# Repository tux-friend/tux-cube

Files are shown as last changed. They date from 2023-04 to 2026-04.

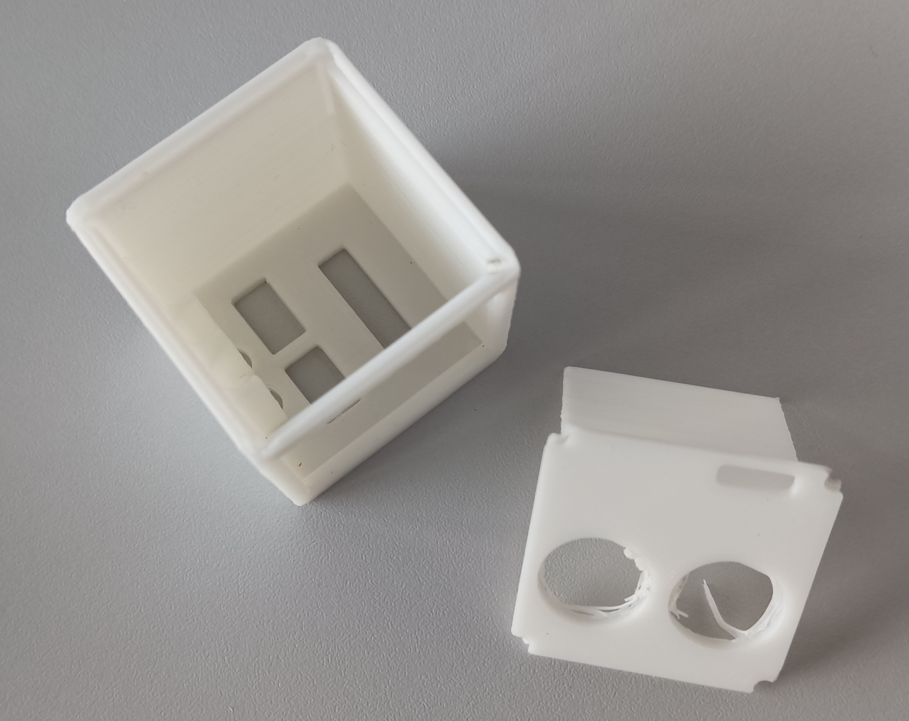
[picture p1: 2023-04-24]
case_v01.jpg

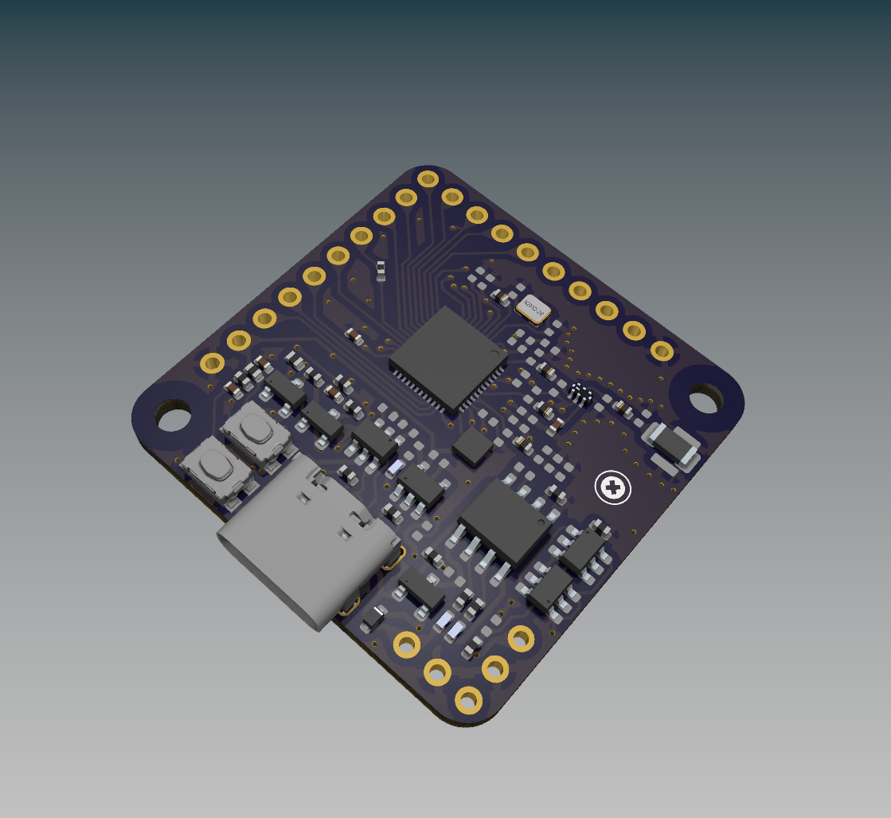
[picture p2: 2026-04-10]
board_front_2.png

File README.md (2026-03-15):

# Physics Sensor Cube ESP32-Tux³

11.04.23 Idea for own ESP32 PCB Design  
15.04.23 First sketches with KiCad  
16.04.23 Idea for physics sensor cube Tux³ and first sketches  
17.04.23 Design and order of v0.1 PCB  
22.04.23 First prototype and proof of concept  
23.04.23 Case v0.1  
25.04.23 Design and order of v0.2 PCB  
25.04.23 Case v0.2  
29.04.23 Software v0.1  
03.05.23 Arrival of PCB v0.1 + v0.2  
10.05.23 Arrival of all parts for PCB, first working ESP32-C3 board  
11.05.23 Order of 30 pcs v0.2 PCB on JLCPCB  
12.05.23 Forth ESP32-C3 board completed  
13.05.23 Case v0.3  
14.05.23 First full prototype &rarr; case too small  
17.05.23 Case v0.4  
21.05.23 ESP32-C3-Tux Mini PCB 20x20mm  
22.05.23 Case v0.5  
27.05.23 Finished DIY Reflow Heat Plate  
31.05.23 Put ESP32-Tux on Tindie and got promotion by [hackster.io](https://www.hackster.io/news/the-lifex-esp32-tux-mini-offers-a-tiny-path-to-energy-harvesting-experimentation-with-an-esp32-c3-0470bf924f33) :-)  
03.06.23 Finished 12 ESP32-Tux Dev boards for Tindie orders  
13.02.24 Designed a ESP32-Tux Board with TP4056 Charging circuit  
15.03.26 Finally got time to get back in the project and designed a new Dev Board with ESP32-C5 chip  

This is an idea I had for some time after playing around with the ESP32 together with sensors, micropython and Phyphox. I started designing a PCB by my own for an ESP32-C3 chip. I want it to be as small as possible and also solar powered. The cube should be energy ,self-sufficient' and used for teaching physics. 

The cube should have the following sensors:
- Temperature, pressure and humidity sensor &rarr; BME280
- Gyroscope for acceleration and orientation measurements &rarr; MPU9250
- Optical/Light sensor (measuring Lux) &rarr; VEML7700
- 2 connectors for temperature probes (DS18B20)
- Voltage and current meter &rarr; INA219
- Time of flight sensor for measuring distances &rarr; VL53L1X
- optional: magnetometer & microphone for sound measurements

In addition the cube should have:
- OLED Display for showing current measurement data/sensor
- RGB-LED (e.g. for showing battery status)
- Push button for changing the sensor/measurement
- Solar cell and LiPo battery
- Pin-header for connecting to cube to a breadboard and use the GPIO Pins
- Mounting nut for placing the cube on a tripod
- On/Off-Button
- optional: buzzer for sound output

I aim for a 35x35x35mm cube with 3D printed case. The case should be robust - so that it can fall from a building and be undamaged... Hope to be able to do this project. 

My inspiration come from the [ESP32-Picoclick-C3](https://github.com/makermoekoe/Picoclick-C3), [BQ25504 Solar Cell LiPo Charger](https://hackaday.io/project/158837-ultra-low-power-lipo-charger-via-energy-harvesting), [01Space-ESP32-C3](https://github.com/01Space/ESP32-C3-0.42LCD) and the [Wemos C3 Pico](https://www.wemos.cc/en/latest/c3/c3_pico.html).

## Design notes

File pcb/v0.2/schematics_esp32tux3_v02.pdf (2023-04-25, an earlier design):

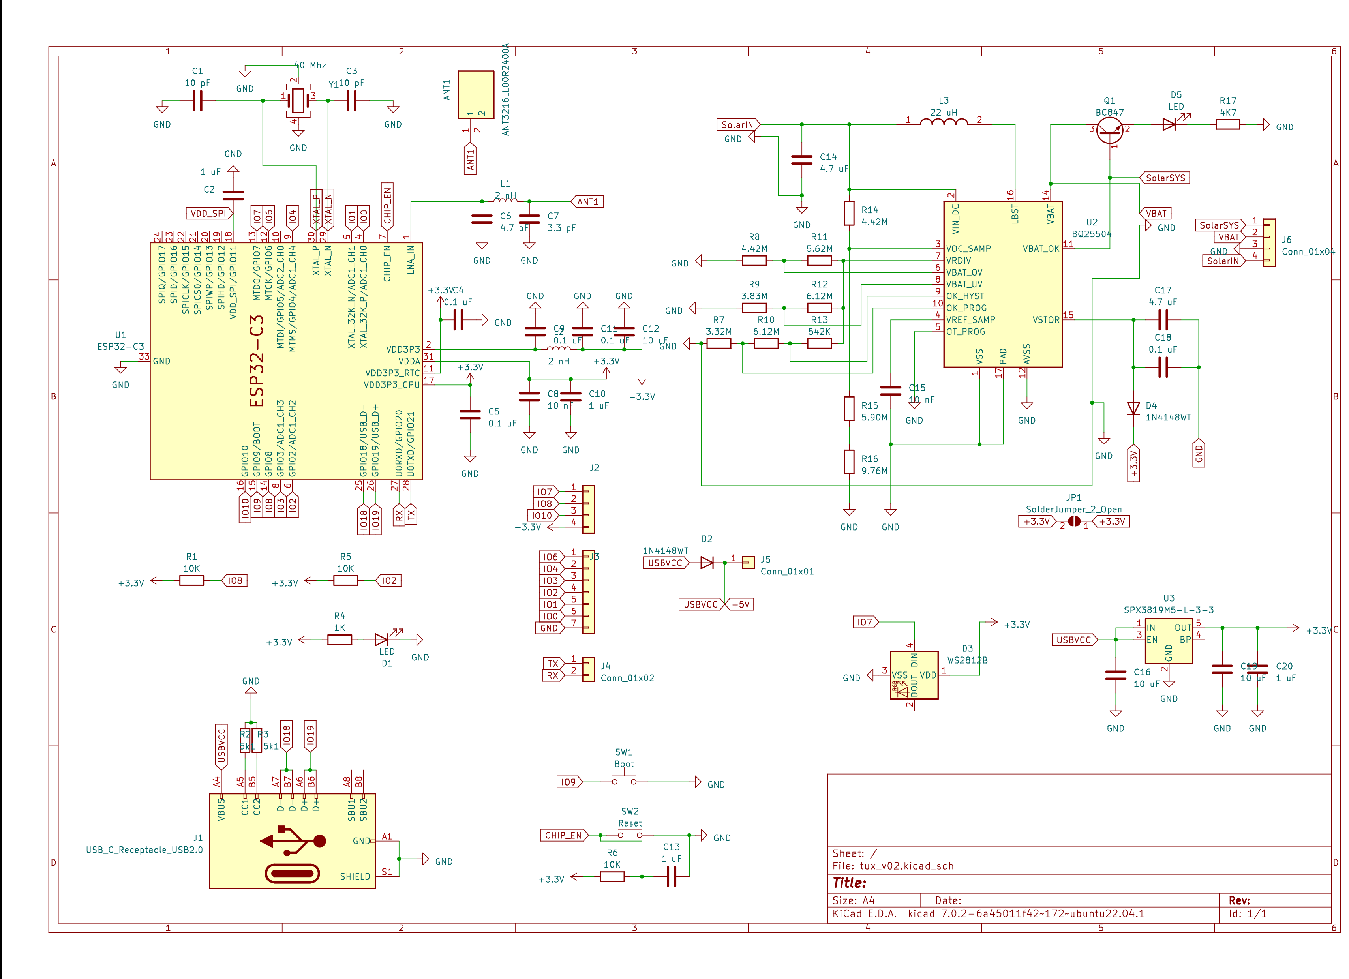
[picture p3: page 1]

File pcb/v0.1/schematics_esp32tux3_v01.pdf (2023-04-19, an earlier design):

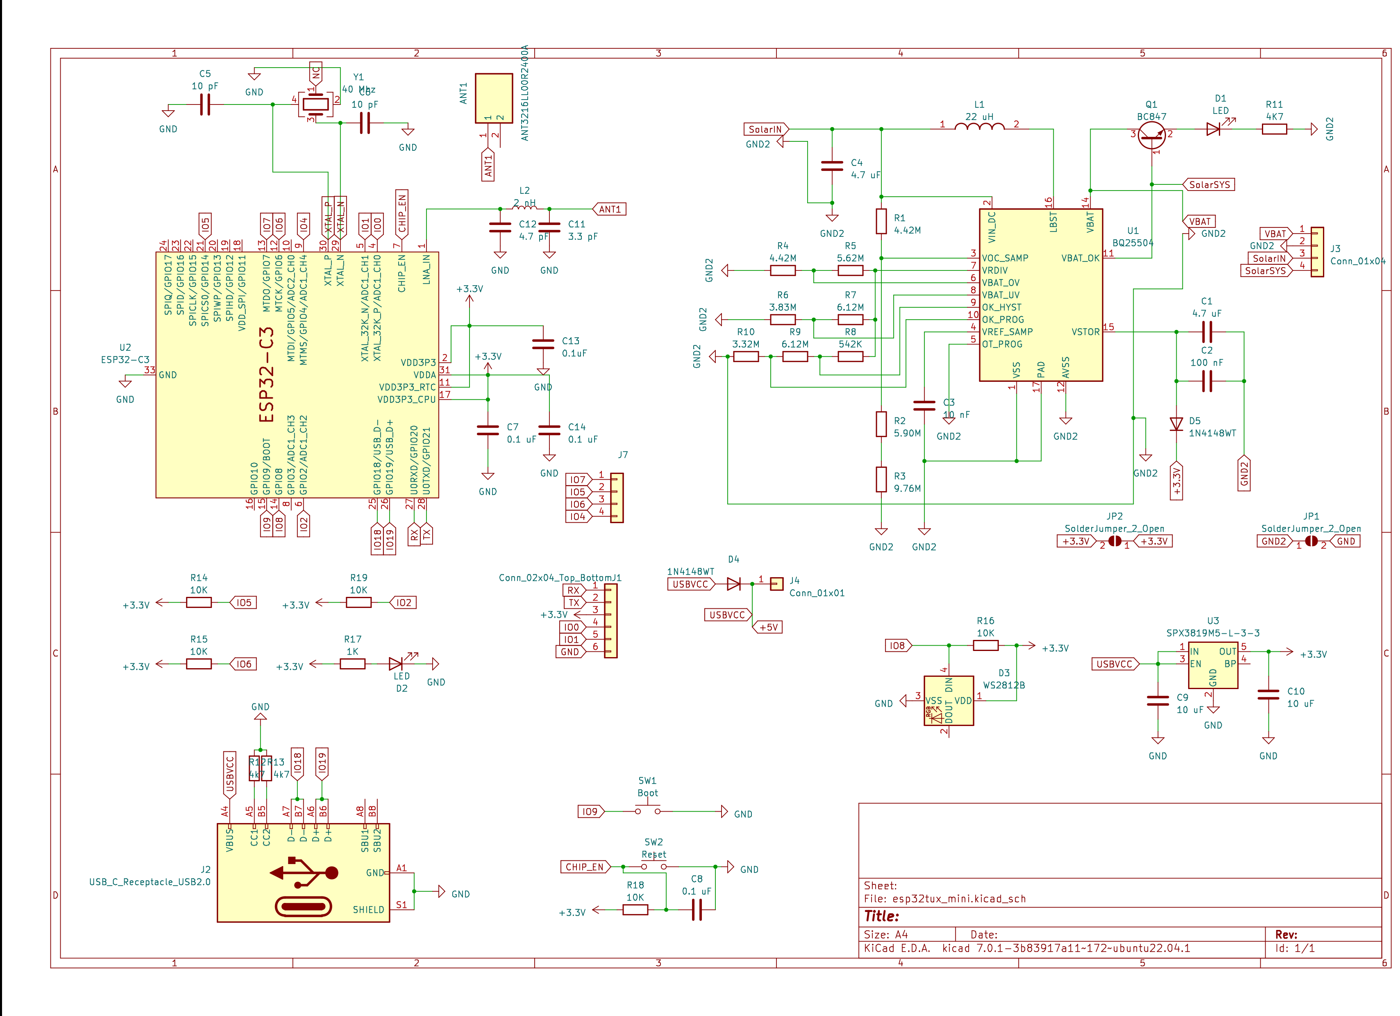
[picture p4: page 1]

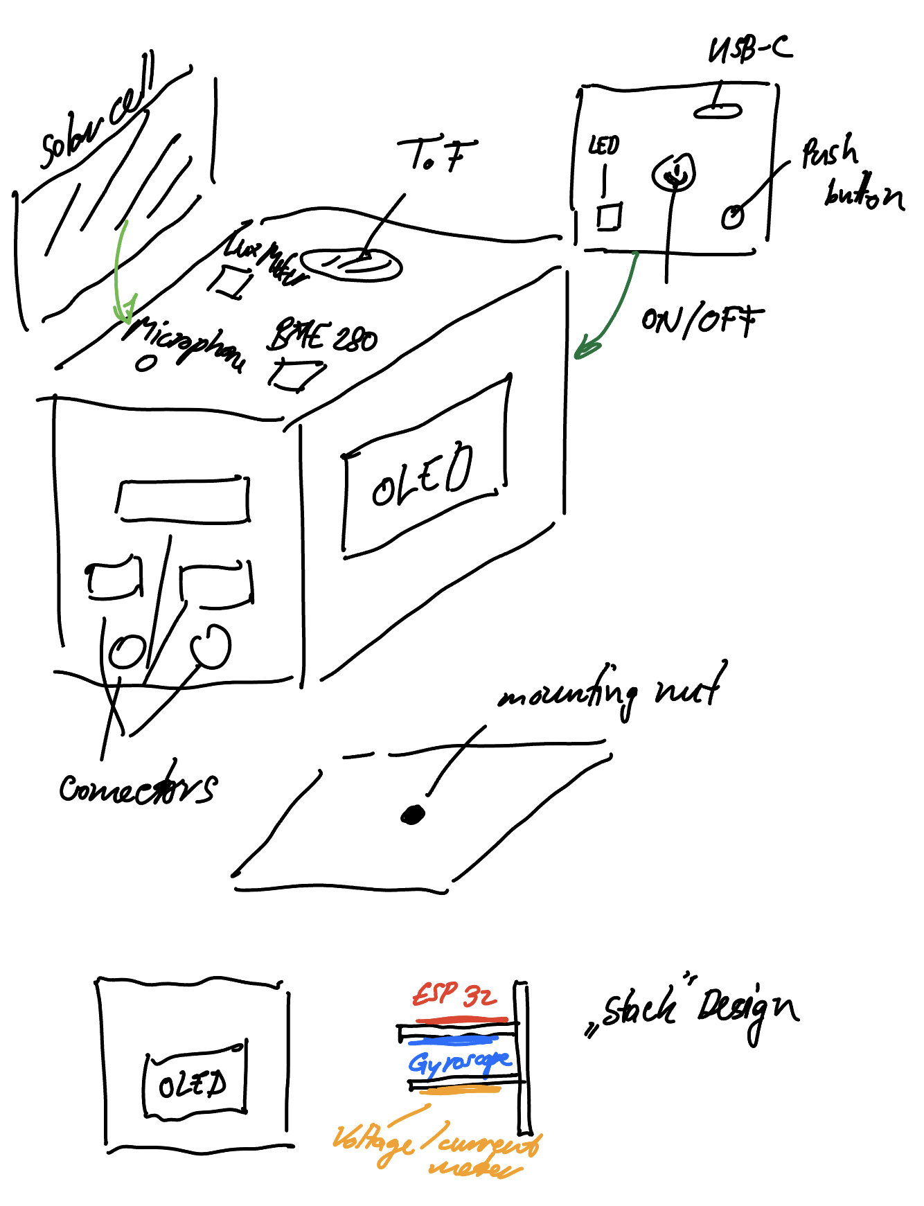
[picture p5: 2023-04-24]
idea_sketch_tux_cube.png

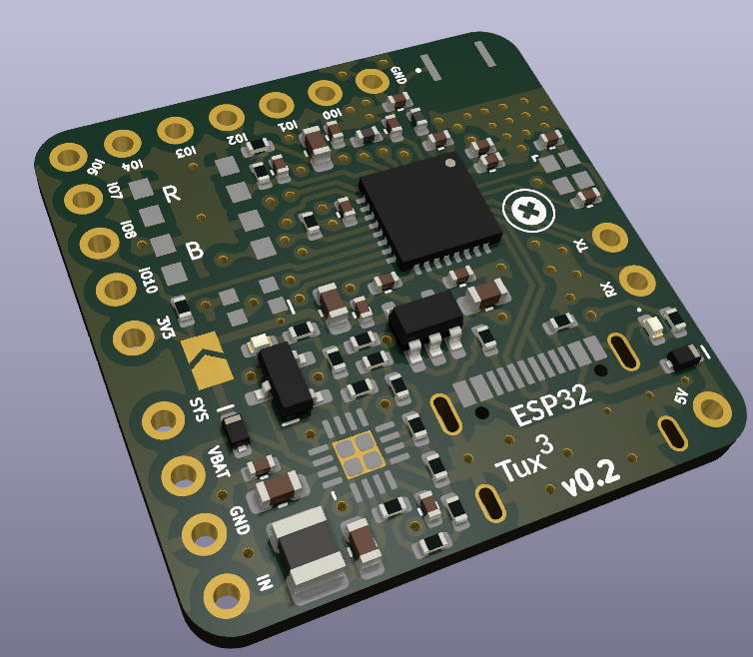
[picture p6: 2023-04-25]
tux_pcb_v02.png

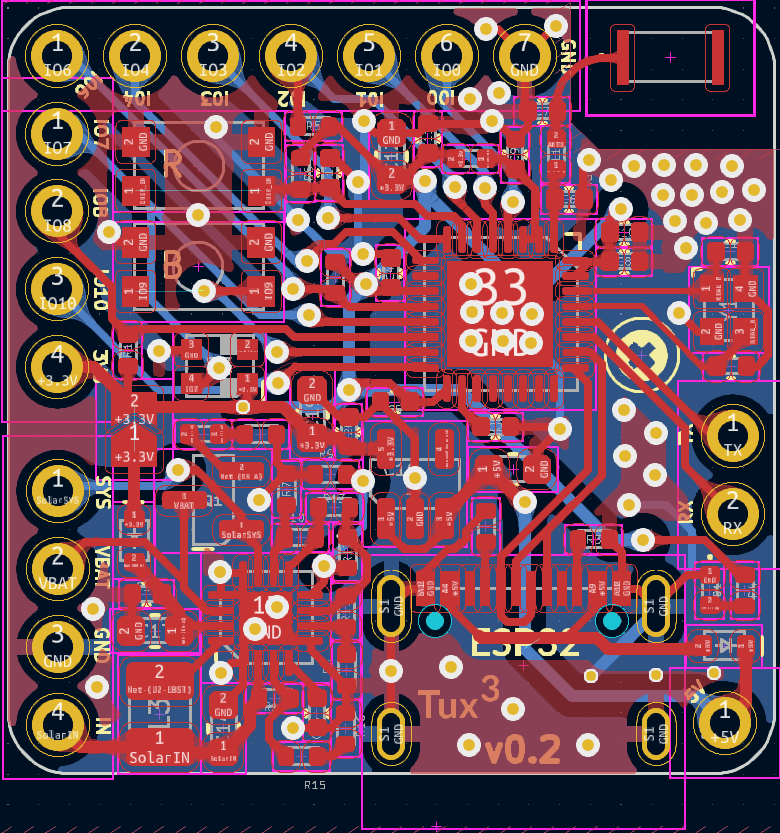
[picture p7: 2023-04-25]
routing_pcb_v02.png

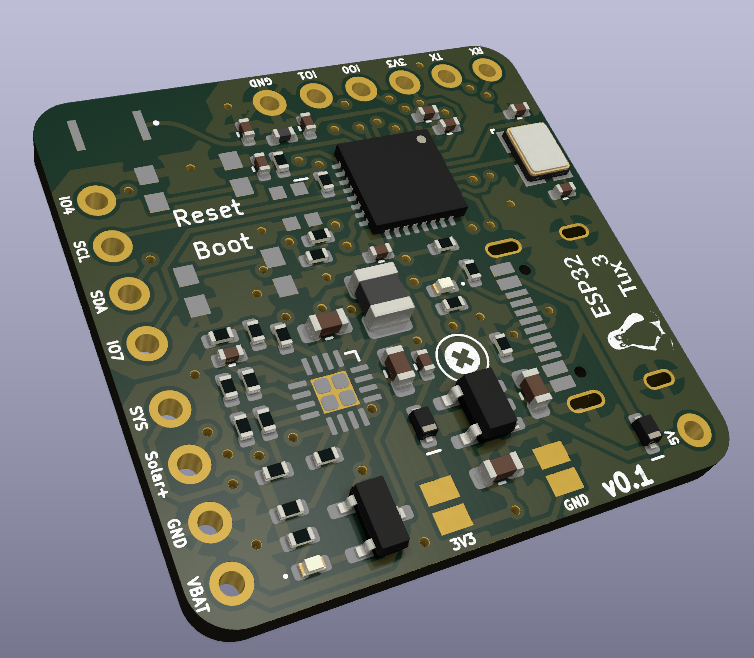
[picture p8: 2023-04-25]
tux_pcb_v01.png

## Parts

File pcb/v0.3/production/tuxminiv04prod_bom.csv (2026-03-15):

Designator | Footprint | Quantity | Value | LCSC Part #
ANT1 | Johanson_2450AT18x100 | 1 | ANT3216LL00R2400A
C1, C14, C15, C19, C2, C27 | 0402 | 6 | 10uF
C10, C11 | 0402 | 2 | 1.2pF
C12 | 0402 | 1 | 1nF
C13, C16, C18, C29 | 0402 | 4 | 1uF
C17, C22, C23, C26, C28 | 0402 | 5 | 0.1uF
C20 | 0402 | 1 | 0.3pF
C21 | 0402 | 1 | 0.8pF
C24 | 0402 | 1 | 2.6pF
C25 | 0402 | 1 | 3.0pF
C3 | 0402 | 1 | 15pF
C31 | 0402 | 1 | 10nF
C4, C5 | 0402 | 2 | 10pF
C6, C7 | 0402 | 2 | 1pF
C8, C9 | 0402 | 2 | 2.2pF
D2, D4, D5 | 0402 | 3 | LED
D6 | D_SOD-523 | 1 | SS34
D7 | LED_SK6812_EC15_1.5x1.5mm | 1 | SK6805
FL1 | LFD182G45DCHD277 | 1 | LFD182G45DCHD277
J1 | USB_C_Receptacle_Palconn_UTC16-G | 1 | USB_C_Receptacle_USB2.0_16P
J3 | PinHeader_1x09_P2.54mm_Vertical | 1 | Conn_01x09
J4 | PinHeader_1x10_P2.54mm_Vertical | 1 | Conn_01x10
J6, J7 | PinHeader_1x02_P2.54mm_Vertical | 2 | Conn_01x02
J8 | PinHeader_1x03_P2.54mm_Vertical | 1 | Conn_01x03
L1 | 0402 | 1 | 24nH
L2, L3, L4 | 0402 | 3 | 2.8nH
L5 | 0402 | 1 | 2.0nH
Q1 | SOT-23 | 1 | DMG1045U
Q2 | SOT-23 | 1 | Si2301CDS
Q3 | SOT-23 | 1 | 2N7002
R1, R2, R7, R8, R9 | 0402 | 5 | 5K1
R10, R13, R14, R15, R16, R5, R6 | 0402 | 7 | 10K
R11 | 0402 | 1 | 1k
R12 | 0402 | 1 | 1k2
R17 | 0402 | 1 | 100K
R18 | 0402 | 1 | 499
R3, R4 | 0402 | 2 | 22
SW1 | SW_Push_1P1T_NO_CK_KMR2 | 1 | Boot
SW2 | SW_Push_1P1T_NO_CK_KMR2 | 1 | Reset
U1 | QFN-48-1EP_6x6mm_P0.4mm_EP4.6x4.6mm | 1 | ESP32-C5
U2 | SOT-23-6 | 1 | USBLC6-2SC6
U4 | SOIC-8-1EP_3.9x4.9mm_P1.27mm_EP2.29x3mm | 1 | TP4056
U5 | SOT-23-6 | 1 | FS8205A
U6 | SOT-23-6 | 1 | DW01
U7 | SOT-23-5 | 1 | XC6220B331MR
Y1 | Crystal_SMD_2016-4Pin_2.0x1.6mm | 1 | Crystal_GND24

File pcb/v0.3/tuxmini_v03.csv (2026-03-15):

Reference | Qty | Value | DNP | Exclude from BOM | Exclude from Board | Footprint
ANT1 | 1 | ANT3216LL00R2400A |  |  |  | RF_Antenna:Johanson_2450AT18x100
C1,C2,C14,C15,C19,C27 | 6 | 10uF |  |  |  | Capacitor_SMD:C_0402_1005Metric
C3 | 1 | 15pF |  |  |  | Capacitor_SMD:C_0402_1005Metric
C4,C5 | 2 | 10pF |  |  |  | Capacitor_SMD:C_0402_1005Metric
C6,C7 | 2 | 1pF |  |  |  | Capacitor_SMD:C_0402_1005Metric
C8,C9 | 2 | 2.2pF |  |  |  | Capacitor_SMD:C_0402_1005Metric
C10,C11 | 2 | 1.2pF |  |  |  | Capacitor_SMD:C_0402_1005Metric
C12 | 1 | 1nF |  |  |  | PCM_SparkFun-Capacitor:C_0402_1005Metric
C13,C16,C18,C29 | 4 | 1uF |  |  |  | Capacitor_SMD:C_0402_1005Metric
C17,C22,C23,C26,C28 | 5 | 0.1uF |  |  |  | Capacitor_SMD:C_0402_1005Metric
C20 | 1 | 0.3pF |  |  |  | Capacitor_SMD:C_0402_1005Metric
C21 | 1 | 0.8pF |  |  |  | Capacitor_SMD:C_0402_1005Metric
C24 | 1 | 2.6pF |  |  |  | Capacitor_SMD:C_0402_1005Metric
C25 | 1 | 3.0pF |  |  |  | Capacitor_SMD:C_0402_1005Metric
C31 | 1 | 10nF |  |  |  | Capacitor_SMD:C_0402_1005Metric
D2,D4,D5 | 3 | LED |  |  |  | LED_SMD:LED_0402_1005Metric
D6 | 1 | SS34 |  |  |  | Diode_SMD:D_SOD-523
D7 | 1 | SK6805 |  |  |  | LED_SMD:LED_SK6812_EC15_1.5x1.5mm
FL1 | 1 | LFD182G45DCHD277 |  |  |  | LFD182G45DCHD277
H1,H2 | 2 | MountingHole |  | Von Bauteilliste ausgeschlossen |  | MountingHole:MountingHole_2.5mm_Pad_Via
J1 | 1 | USB_C_Receptacle_USB2.0_16P |  |  |  | Connector_USB:USB_C_Receptacle_Palconn_UTC16-G
J3 | 1 | Conn_01x09 |  |  |  | Connector_PinHeader_2.54mm:PinHeader_1x09_P2.54mm_Vertical
J4 | 1 | Conn_01x10 |  |  |  | Connector_PinHeader_2.54mm:PinHeader_1x10_P2.54mm_Vertical
J6,J7 | 2 | Conn_01x02 |  |  |  | Connector_PinHeader_2.54mm:PinHeader_1x02_P2.54mm_Vertical
J8 | 1 | Conn_01x03 |  |  |  | Connector_PinHeader_2.54mm:PinHeader_1x03_P2.54mm_Vertical
L1 | 1 | 24nH |  |  |  | Inductor_SMD:L_0402_1005Metric
L2,L3,L4 | 3 | 2.8nH |  |  |  | Inductor_SMD:L_0402_1005Metric
L5 | 1 | 2.0nH |  |  |  | Inductor_SMD:L_0402_1005Metric
Q1 | 1 | DMG1045U |  |  |  | PCM_Package_TO_SOT_SMD_AKL:SOT-23
Q2 | 1 | Si2301CDS |  |  |  | PCM_Package_TO_SOT_SMD_AKL:SOT-23
Q3 | 1 | 2N7002 |  |  |  | PCM_Package_TO_SOT_SMD_AKL:SOT-23
R1,R2,R7,R8,R9 | 5 | 5K1 |  |  |  | Resistor_SMD:R_0402_1005Metric
R3,R4 | 2 | 22 |  |  |  | Resistor_SMD:R_0402_1005Metric
R5,R6,R10,R13,R14,R15,R16 | 7 | 10K |  |  |  | PCM_Resistor_SMD_AKL:R_0402_1005Metric,Resistor_SMD:R_0402_1005Metric
R11 | 1 | 1k |  |  |  | Resistor_SMD:R_0402_1005Metric
R12 | 1 | 1k2 |  |  |  | Resistor_SMD:R_0402_1005Metric
R17 | 1 | 100K |  |  |  | PCM_Resistor_SMD_AKL:R_0402_1005Metric
R18 | 1 | 499 |  |  |  | Resistor_SMD:R_0402_1005Metric
SW1 | 1 | Boot |  |  |  | Button_Switch_SMD:SW_Push_1P1T_NO_CK_KMR2
SW2 | 1 | Reset |  |  |  | Button_Switch_SMD:SW_Push_1P1T_NO_CK_KMR2
U1 | 1 | ESP32-C5 |  |  |  | Package_DFN_QFN:QFN-48-1EP_6x6mm_P0.4mm_EP4.6x4.6mm
U2 | 1 | USBLC6-2SC6 |  |  |  | Package_TO_SOT_SMD:SOT-23-6
U4 | 1 | TP4056 |  |  |  | Package_SO:SOIC-8-1EP_3.9x4.9mm_P1.27mm_EP2.29x3mm
U5 | 1 | FS8205A |  |  |  | Package_TO_SOT_SMD:SOT-23-6
U6 | 1 | DW01 |  |  |  | Package_TO_SOT_SMD:SOT-23-6
U7 | 1 | XC6220B331MR |  |  |  | Package_TO_SOT_SMD:SOT-23-5
Y1 | 1 | Crystal_GND24 |  |  |  | Crystal:Crystal_SMD_2016-4Pin_2.0x1.6mm

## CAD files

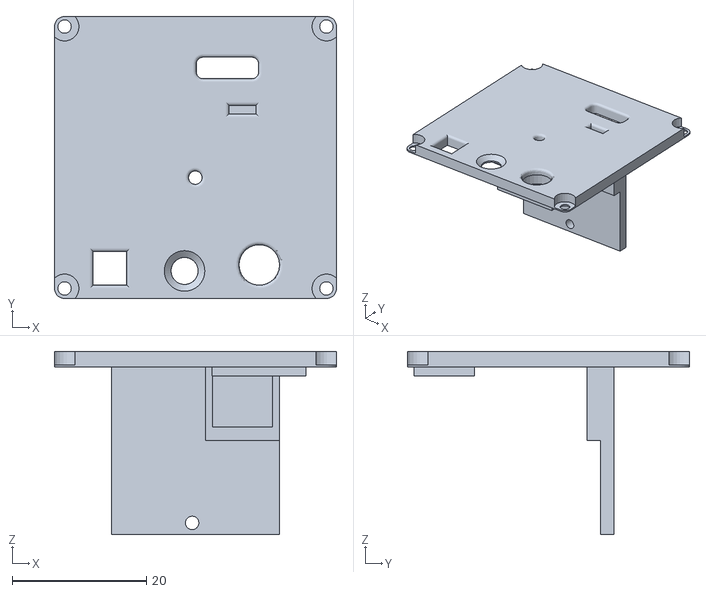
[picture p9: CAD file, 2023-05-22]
case/cube_inside.stl
42.0 x 42.0 x 27.3

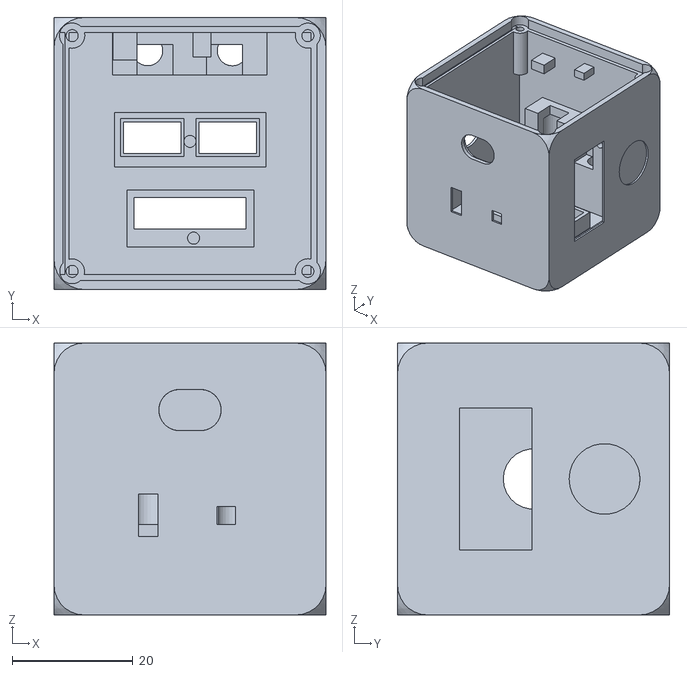
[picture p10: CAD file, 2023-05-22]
case/cube_outside.stl
45.0 x 45.0 x 45.0

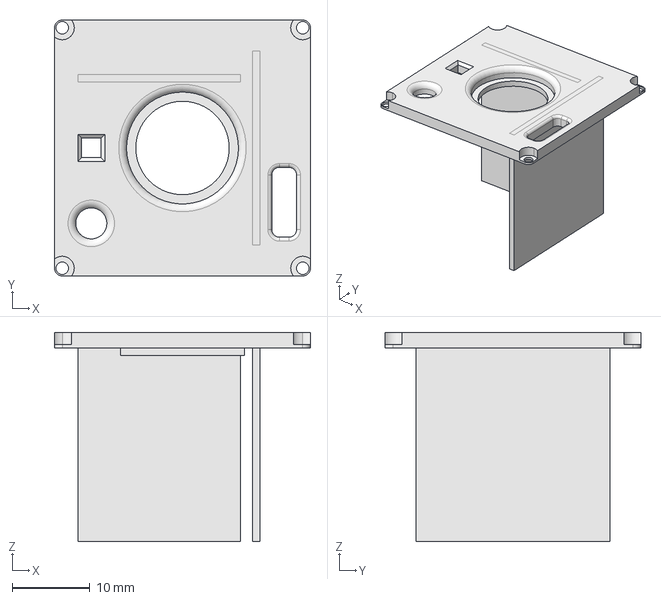
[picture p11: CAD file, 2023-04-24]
case/TuxCube3_case_v01.FCStd
33.0 x 33.0 x 27.0 mm

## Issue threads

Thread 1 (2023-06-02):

Quiescent current from the LED Pixel?

EternityForest, 2023-06-02:
As I understand it those chips use 250uA or so when idle?  Seems like a significant load in this kind of application.

Could a MOSFET be used to stop this idle drain?

tux-friend, 2023-06-03:
This is true. It's my first ESP32 PCB design and I didn't focus on power efficency - but for a revision of the board I sure will take this into consideration.
The sensor cube uses Bluetooth Low Energy and then the ESP32 uses quite a lot of power. For a 24/7 usage of the board the LED could also be soldered of or yes maybe a MOSFET.

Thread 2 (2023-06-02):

Put all the indicator LEDs under software control?

EternityForest, 2023-06-02:
Right now there's LEDs for VBAT and 3.3v power, which seems like a pretty heavy power drain, plus an aesthetic issue if they are too bright when that's not wanted.

Maybe VBAT_OK could be connected to an IO, or better yet, a 10Mohm voltage divider and 0.1uf capacitor could be used to let the ESP measure the battery with an ADC, and any indicator lights desired could be done in software?

Since there's already an addressable LED pixel, maybe that could be used, and the different battery status conditions indicated just via blink patterns.

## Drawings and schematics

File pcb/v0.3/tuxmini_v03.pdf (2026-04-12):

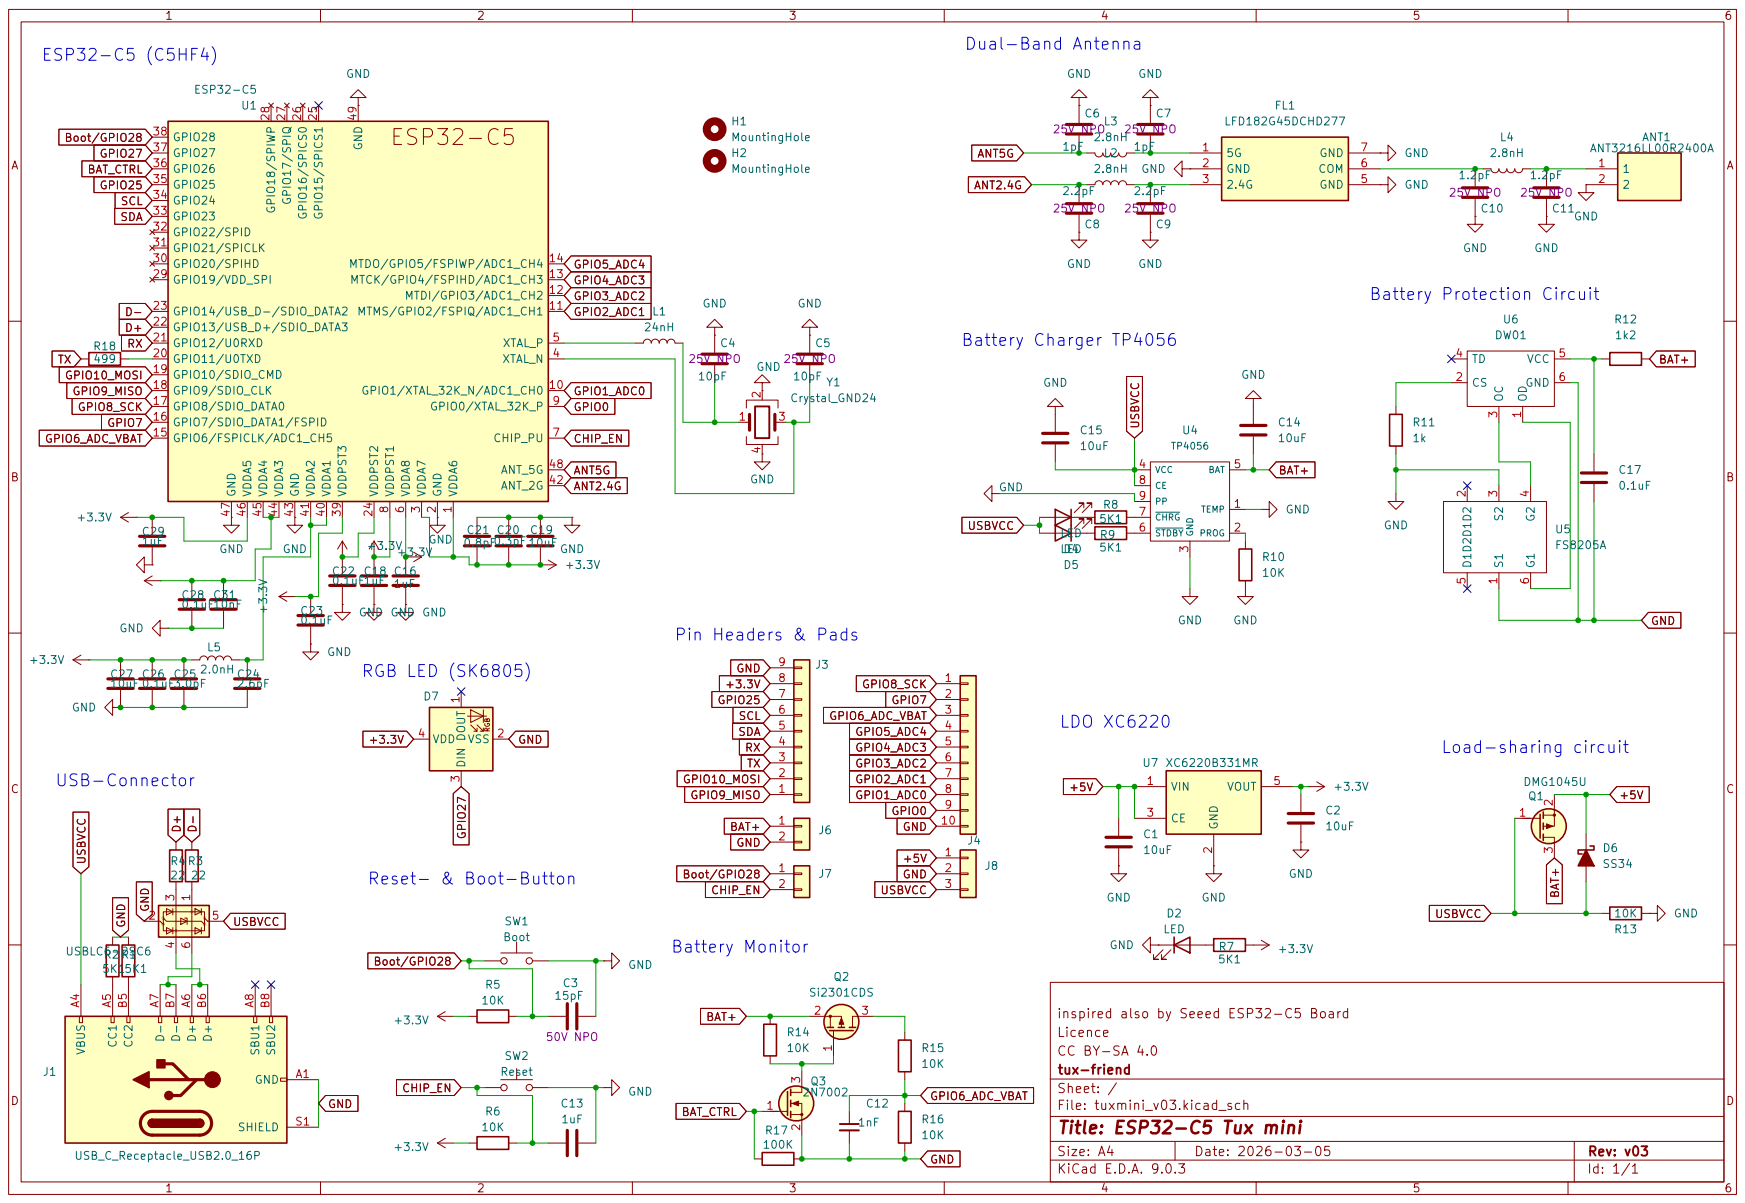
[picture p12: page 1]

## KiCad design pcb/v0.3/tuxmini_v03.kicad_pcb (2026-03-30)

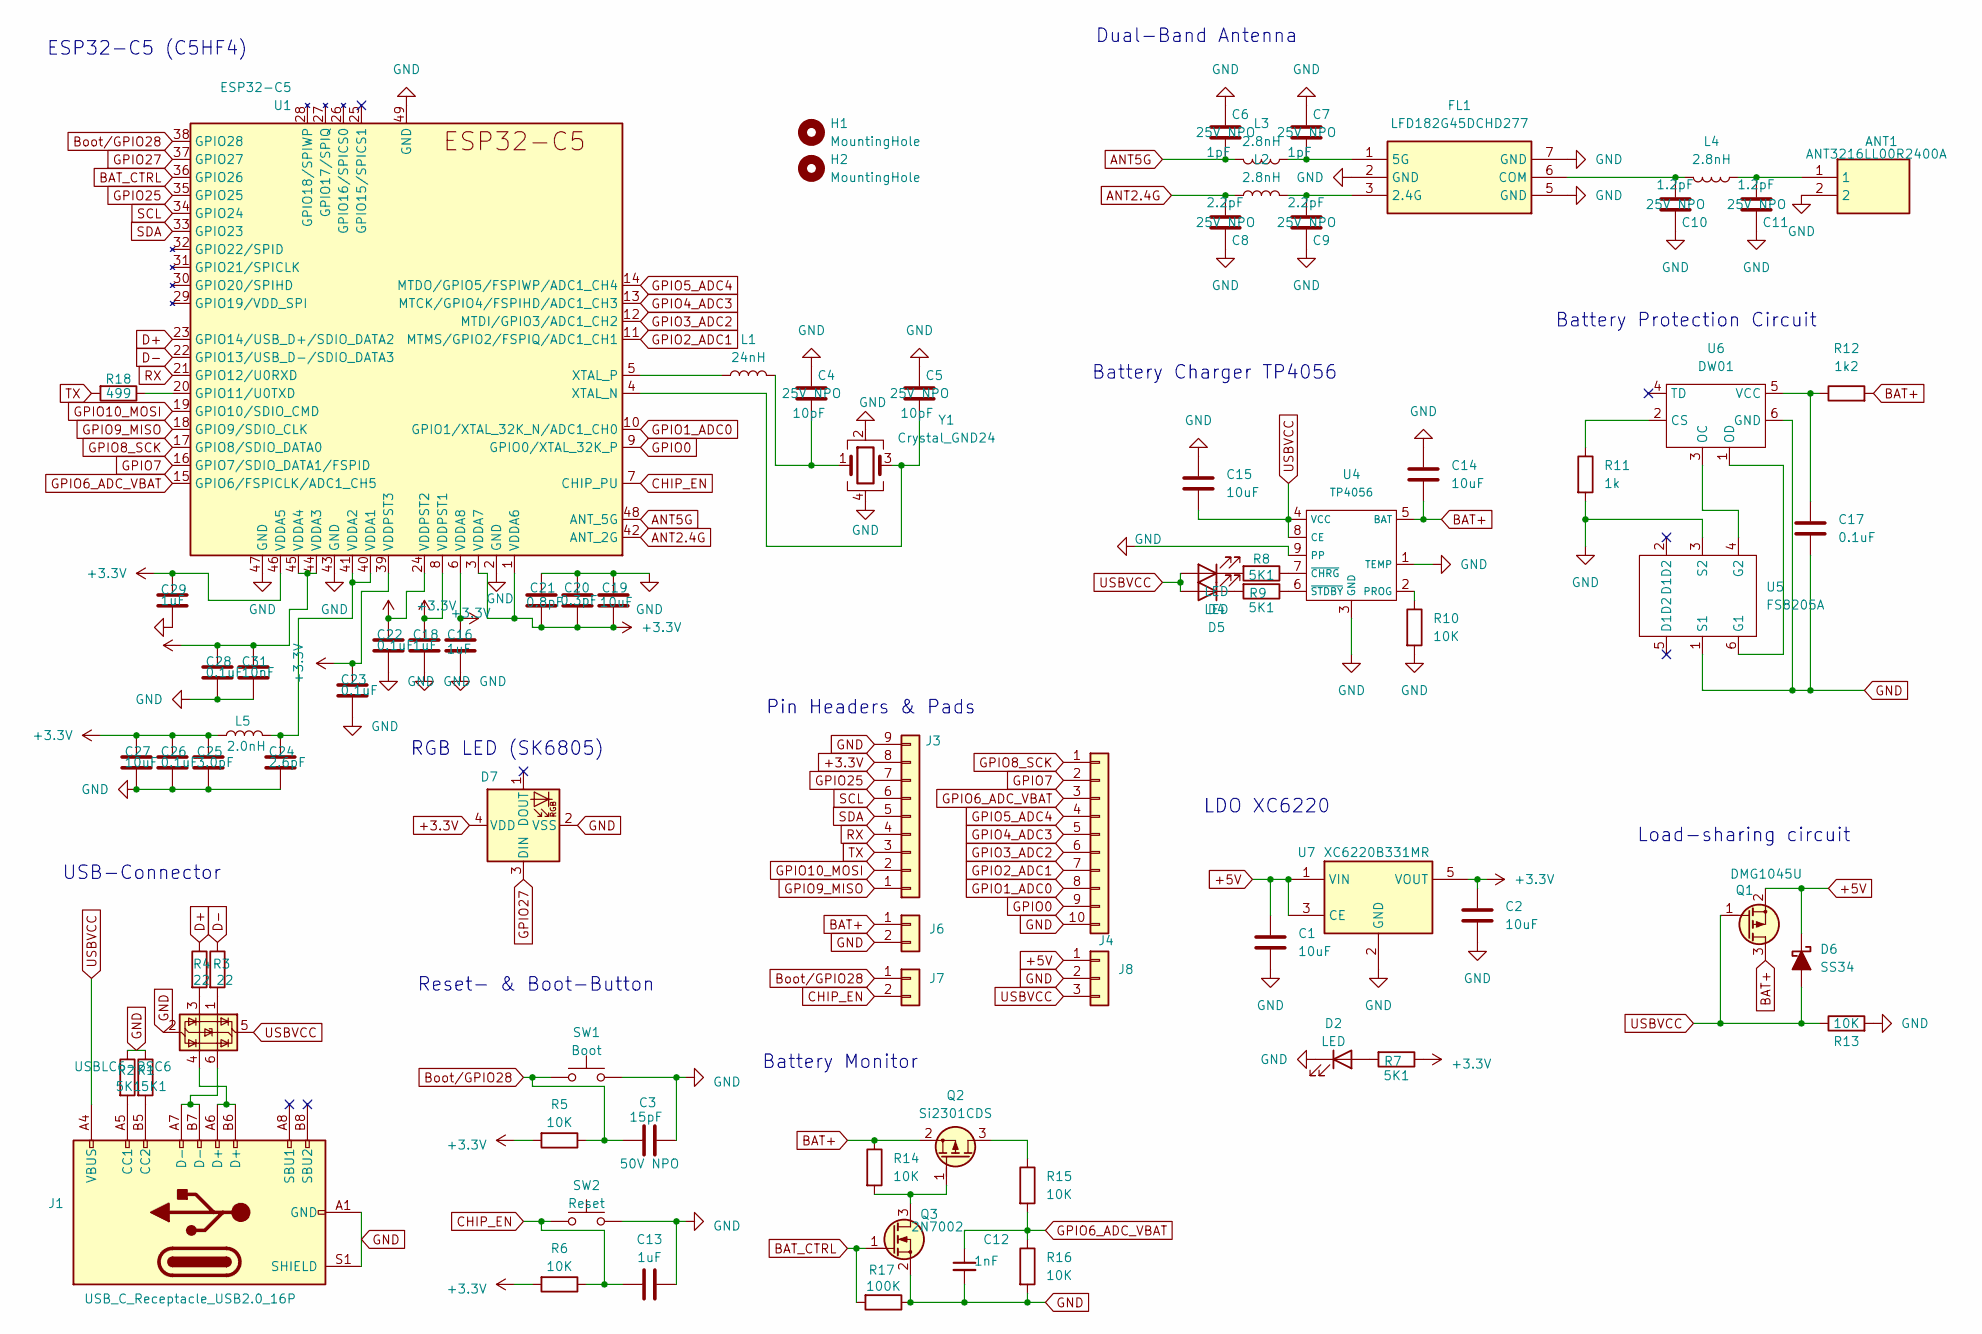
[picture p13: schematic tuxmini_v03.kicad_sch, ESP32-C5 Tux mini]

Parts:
ANT1: ANT3216LL00R2400A; Johanson_2450AT18x100; Mouser Part Number 603-ANT3216LL00R2400
C1, C2, C14, C15, C19, C27: 10uF; C_0402_1005Metric
C3: 15pF; C_0402_1005Metric
C4, C5: 10pF; C_0402_1005Metric
C6, C7: 1pF; C_0402_1005Metric
C8, C9: 2.2pF; C_0402_1005Metric
C10, C11: 1.2pF; C_0402_1005Metric
C12: 1nF; C_0402_1005Metric; Tolerance 100%
C13, C16, C18, C29: 1uF; C_0402_1005Metric
C17, C22, C23, C26, C28: 0.1uF; C_0402_1005Metric
C20: 0.3pF; C_0402_1005Metric
C21: 0.8pF; C_0402_1005Metric
C24: 2.6pF; C_0402_1005Metric
C25: 3.0pF; C_0402_1005Metric
C31: 10nF; C_0402_1005Metric
D2, D4, D5: LED; LED_0402_1005Metric
D6: SS34; D_SOD-523
D7: SK6805; LED_SK6812_EC15_1.5x1.5mm
FL1: LFD182G45DCHD277; Manufacturer_Part_Number LFD182G45DCHD277
H1, H2: MountingHole; MountingHole_2.5mm_Pad_Via
J1: USB_C_Receptacle_USB2.0_16P; USB_C_Receptacle_Palconn_UTC16-G
J3: Conn_01x09; PinHeader_1x09_P2.54mm_Vertical
J4: Conn_01x10; PinHeader_1x10_P2.54mm_Vertical
J6: Conn_01x02; PinHeader_1x02_P2.54mm_Vertical; Part Number 1-0201FBV0T
J7: Conn_01x02; PinHeader_1x02_P2.54mm_Vertical
J8: Conn_01x03; PinHeader_1x03_P2.54mm_Vertical
L1: 24nH; L_0402_1005Metric
L2, L3, L4: 2.8nH; L_0402_1005Metric
L5: 2.0nH; L_0402_1005Metric
Q1: DMG1045U; SOT-23
Q2: Si2301CDS; SOT-23
Q3: 2N7002; SOT-23
R1, R2, R7, R8, R9: 5K1; R_0402_1005Metric
R3, R4: 22; R_0402_1005Metric
R5, R6, R10, R13, R14, R15, R16: 10K; R_0402_1005Metric
R11: 1k; R_0402_1005Metric
R12: 1k2; R_0402_1005Metric
R17: 100K; R_0402_1005Metric
R18: 499; R_0402_1005Metric
SW1: Boot; SW_Push_1P1T_NO_CK_KMR2
SW2: Reset; SW_Push_1P1T_NO_CK_KMR2
U1: ESP32-C5; QFN-48-1EP_6x6mm_P0.4mm_EP4.6x4.6mm
U2: USBLC6-2SC6; SOT-23-6
U4: TP4056; SOIC-8-1EP_3.9x4.9mm_P1.27mm_EP2.29x3mm
U5: FS8205A; SOT-23-6
U6: DW01; SOT-23-6
U7: XC6220B331MR; SOT-23-5
Y1: Crystal_GND24; Crystal_SMD_2016-4Pin_2.0x1.6mm

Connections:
+3.3V: C2.1, C16.1, C18.1, C19.2, C20.2, C21.2, C22.1, C23.1, C25.1, C26.1, C27.1, C28.1, C29.1, C31.1, D7.4 (VDD), J3.8, L5.2, R5.2, R6.2, R7.1, U1.1 (VDDA6), U1.3 (VDDA7), U1.6 (VDDA8), U1.8 (VDDPST1), U1.24 (VDDPST2), U1.39 (VDDPST3), U1.44 (VDDA3), U1.45 (VDDA4), U1.46 (VDDA5), U7.5 (VOUT)
+5V: C1.1, D6.1 (K), J8.1, Q1.2 (S), U7.1 (VIN), U7.3 (CE)
ANT2.4G: C8.2, L2.2, U1.42 (ANT_2G)
ANT5G: C6.2, L3.2, U1.48 (ANT_5G)
BAT+: C14.2, J6.1, Q1.3 (D), Q2.2 (S), R12.2, R14.1, U4.5 (BAT)
BAT_CTRL: Q3.1 (G), R17.2, U1.36 (GPIO26)
Boot/GPIO28: C3.1, J7.1, R5.1, SW1.1, U1.38 (GPIO28)
CHIP_EN: C13.1, J7.2, R6.1, SW2.1, U1.7 (CHIP_PU)
D+: R4.1, U1.23 (GPIO14/USB_D+/SDIO_DATA2)
D-: R3.1, U1.22 (GPIO13/USB_D-/SDIO_DATA3)
GND: ANT1.2, C1.2, C2.2, C3.2, C4.1, C5.1, C6.1, C7.1, C8.1, C9.1, C10.1, C11.1, C12.2, C13.2, C14.1, C15.1, C16.2, C17.2, C18.2, C19.1, C20.1, C21.1, C22.2, C23.2, C24.2, C25.2, C26.2, C27.2, C28.2, C29.2, C31.2, D2.1 (K), D7.2 (VSS), FL1.2 (GND), FL1.5 (GND), FL1.7 (GND), J1.A1 (GND), J1.A12 (GND), J1.B1 (GND), J1.B12 (GND), J1.S1 (SHIELD), J3.9, J4.10, J6.2, J8.2, Q3.2 (S), R1.1, R2.1, R10.2, R11.2, R13.2, R16.2, R17.1, SW1.2, SW2.2, U1.2 (GND), U1.43 (GND), U1.47 (GND), U1.49 (GND), U2.2 (GND), U4.1 (TEMP), U4.3 (GND), U4.9 (PP), U5.1 (S1), U5.3 (S2), U6.6 (GND), U7.2 (GND), Y1.2, Y1.4
GPIO0: J4.9, U1.9 (GPIO0/XTAL_32K_P)
GPIO1_ADC0: J4.8, U1.10 (GPIO1/XTAL_32K_N/ADC1_CH0)
GPIO2_ADC1: J4.7, U1.11 (MTMS/GPIO2/FSPIQ/ADC1_CH1)
GPIO3_ADC2: J4.6, U1.12 (MTDI/GPIO3/ADC1_CH2)
GPIO4_ADC3: J4.5, U1.13 (MTCK/GPIO4/FSPIHD/ADC1_CH3)
GPIO5_ADC4: J4.4, U1.14 (MTDO/GPIO5/FSPIWP/ADC1_CH4)
GPIO6_ADC_VBAT: C12.1, J4.3, R15.2, R16.1, U1.15 (GPIO6/FSPICLK/ADC1_CH5)
GPIO7: J4.2, U1.16 (GPIO7/SDIO_DATA1/FSPID)
GPIO8_SCK: J4.1, U1.17 (GPIO8/SDIO_DATA0)
GPIO9_MISO: J3.1, U1.18 (GPIO9/SDIO_CLK)
GPIO10_MOSI: J3.2, U1.19 (GPIO10/SDIO_CMD)
GPIO25: J3.7, U1.35 (GPIO25)
GPIO27: D7.3 (DIN), U1.37 (GPIO27)
unnamed: ANT1.1, C11.2, L4.2
unnamed: C4.2, L1.2, Y1.1
unnamed: D2.2 (A), R7.2
unnamed: D4.1 (K), R8.2
unnamed: D5.1 (K), R9.2
unnamed: C9.2, FL1.3 (2.4G), L2.1
unnamed: C7.2, FL1.1 (5G), L3.1
unnamed: C10.2, FL1.6 (COM), L4.1
unnamed: J1.A5 (CC1), R2.2
unnamed: J1.B5 (CC2), R1.2
unnamed: J1.A6 (D+), J1.B6 (D+), U2.4 (I/O2)
unnamed: J1.A7 (D-), J1.B7 (D-), U2.6 (I/O1)
unnamed: Q2.3 (D), R15.1
unnamed: Q2.1 (G), Q3.3 (D), R14.2
unnamed: R3.2, U2.1 (I/O1)
unnamed: R4.2, U2.3 (I/O2)
unnamed: R18.1, U1.20 (GPIO11/U0TXD)
unnamed: C24.1, L5.1, U1.40 (VDDA1), U1.41 (VDDA2)
unnamed: C5.2, U1.4 (XTAL_N), Y1.3
unnamed: L1.1, U1.5 (XTAL_P)
unnamed: R10.1, U4.2 (PROG)
unnamed: R8.1, U4.7 (~CHRG)
unnamed: R9.1, U4.6 (~STDBY)
unnamed: U5.6 (G1), U6.1 (OD)
unnamed: U5.4 (G2), U6.3 (OC)
unnamed: R11.1, U6.2 (CS)
unnamed: C17.1, R12.1, U6.5 (VCC)
RX: J3.4, U1.21 (GPIO12/U0RXD)
SCL: J3.6, U1.34 (GPIO24)
SDA: J3.5, U1.33 (GPIO23)
TX: J3.3, R18.2
USBVCC: C15.2, D4.2 (A), D5.2 (A), D6.2 (A), J1.A4 (VBUS), J1.A9 (VBUS), J1.B4 (VBUS), J1.B9 (VBUS), J8.3, Q1.1 (G), R13.1, U2.5 (VBUS), U4.4 (VCC), U4.8 (CE)

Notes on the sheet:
Reset- & Boot-Button
Battery Monitor
Battery Protection Circuit
LDO XC6220
Load-sharing circuit
Pin Headers & Pads
RGB LED (SK6805)
USB-Connector
ESP32-C5 (C5HF4)
Battery Charger TP4056
Dual-Band Antenna

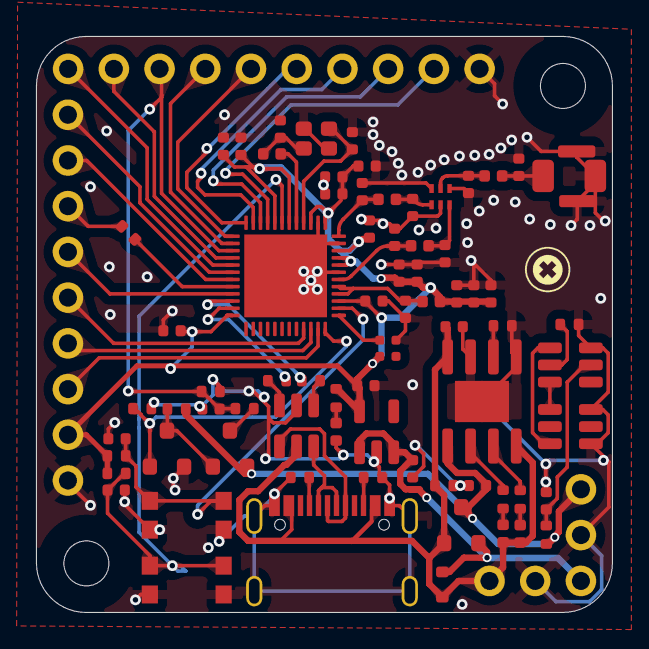
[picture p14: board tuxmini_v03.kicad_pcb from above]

Board: 2 copper layers, 32.0 x 32.0 mm, 80 parts (1 on the bottom side), 56 nets.

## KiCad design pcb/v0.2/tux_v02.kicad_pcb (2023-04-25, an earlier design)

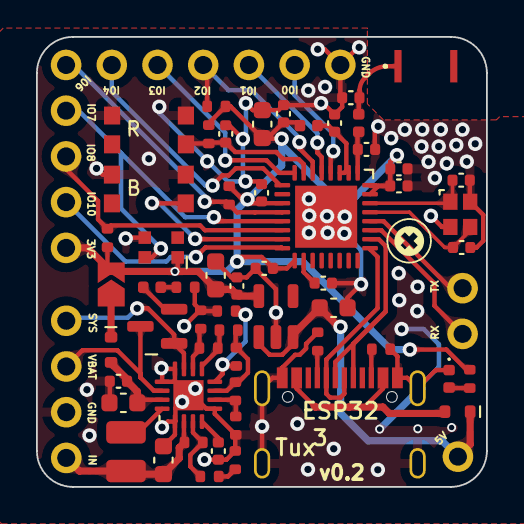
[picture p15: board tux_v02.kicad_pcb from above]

Board: 2 copper layers, 25.0 x 25.0 mm, 61 parts (0 on the bottom side), 42 nets.

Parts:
ANT1: ANT3216LL00R2400A
C1, C3: 10 pF; C_0402_1005Metric
C2, C10, C13, C20: 1 uF; C_0402_1005Metric
C4, C5, C9, C11, C18: 0.1 uF; C_0402_1005Metric
C6: 4.7 pF; C_0402_1005Metric
C7: 3.3 pF; C_0402_1005Metric
C8, C15: 10 nF; C_0402_1005Metric
C12, C16, C19: 10 uF; C_0603_1608Metric
C14, C17: 4.7 uF; C_0603_1608Metric
D1, D5: LED; LED_0402_1005Metric
D2, D4: 1N4148WT; D_SOD-523
D3: WS2812B; LED_WS2812B-2020_PLCC4_2.0x2.0mm
J1: USB_C_Receptacle_USB2.0; USB_C_Receptacle_Palconn_UTC16-G
J2: Conn_02x04_Top_Bottom; PinHeader_1x04_P2.54mm_Vertical
J3: Conn_02x04_Top_Bottom; PinHeader_1x07_P2.54mm_Vertical
J4: Conn_01x02; PinHeader_1x02_P2.54mm_Vertical
J5: Conn_01x01; PinHeader_1x01_P2.54mm_Vertical
J6: Conn_01x04; PinHeader_1x04_P2.54mm_Vertical
JP1: SolderJumper_2_Open; SolderJumper-2_P1.3mm_Open_TrianglePad1.0x1.5mm
L1, L2: 2 nH; L_0402_1005Metric
L3: 22 uH; L_1008_2520Metric
Q1: BC847; SOT-23
R1, R2, R5, R6: 10K; R_0402_1005Metric
R2#2, R3: 5k1; R_0402_1005Metric
R4: 1K; R_0402_1005Metric
R7: 3.32M; R_0402_1005Metric
R8, R14: 4.42M; R_0402_1005Metric
R9: 3.83M; R_0402_1005Metric
R10, R12: 6.12M; R_0402_1005Metric
R11: 5.62M; R_0402_1005Metric
R13: 542K; R_0402_1005Metric
R15: 5.90M; R_0402_1005Metric
R16: 9.76M; R_0402_1005Metric
R17: 4K7; R_0402_1005Metric
SW1: B; SW_Push_1P1T_NO_CK_KMR2
SW2: R; SW_Push_1P1T_NO_CK_KMR2
U1: ESP32-C3; QFN-32-1EP_5x5mm_P0.5mm_EP3.45x3.45mm
U2: BQ25504; VQFN-16-1EP_3x3mm_P0.5mm_EP1.68x1.68mm
U3: SPX3819M5-L-3-3; SOT-23-5
Y1: 40 Mhz; Crystal_SMD_2016-4Pin_2.0x1.6mm

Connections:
+3.3V: C4.1, C5.1, C8.1, C10.1, C11.2, C12.2, C19.1, C20.1, D3.1 (VDD), D4.1 (K), J2.4, JP1.1 (A), JP1.2 (B), L2.2, R1.2, R2.2, R4.2, R5.2, R6.2, U1.11 (VDD3P3_RTC), U1.17 (VDD3P3_CPU), U1.31 (VDDA), U1.32 (VDDA), U3.5 (OUT)
+5V: C16.1, D2.1 (K), D2.2 (A), J1.A4 (VBUS), J1.A9 (VBUS), J1.B4 (VBUS), J1.B9 (VBUS), J5.1, U3.1 (IN), U3.3 (EN)
ANT1: ANT1.1, C7.1, L1.2
CHIP_EN: C13.1, R6.1, SW2.1, U1.7 (CHIP_EN)
GND: C1.2, C2.2, C3.1, C4.2, C5.2, C6.2, C7.2, C8.2, C9.1, C10.2, C11.1, C12.1, C13.2, C14.2, C15.2, C16.2, C17.2, C18.2, C19.2, C20.2, D1.1 (K), D3.3 (VSS), J1.A1 (GND), J1.A12 (GND), J1.B1 (GND), J1.B12 (GND), J1.S1 (SHIELD), J3.7, J6.3, R2#2.1, R3.1, R7.2, R8.2, R9.2, R16.2, R17.1, SW1.2, SW2.2, U1.33 (GND), U2.1 (VSS), U2.5 (OT_PROG), U2.12 (AVSS), U2.13 (VSS), U2.17 (PAD), U3.2 (GND), Y1.2, Y1.4
IO0: J3.6, U1.4 (XTAL_32K_P/ADC1_CH0)
IO1: J3.5, U1.5 (XTAL_32K_N/ADC1_CH1)
IO2: J3.4, R5.1, U1.6 (GPIO2/ADC1_CH2)
IO3: J3.3, U1.8 (GPIO3/ADC1_CH3)
IO4: J3.2, U1.9 (MTMS/GPIO4/ADC1_CH4)
IO6: J3.1, R2.1, U1.12 (MTCK/GPIO6)
IO7: D3.4 (DIN), J2.1, U1.13 (MTDO/GPIO7)
IO8: J2.2, R1.1, U1.14 (GPIO8)
IO9: SW1.1, U1.15 (GPIO9/BOOT)
IO10: J2.3, U1.16 (GPIO10)
IO18: J1.A7 (D-), J1.B7 (D-), U1.25 (GPIO18/USB_D-)
IO19: J1.A6 (D+), J1.B6 (D+), U1.26 (GPIO19/USB_D+)
unnamed: C9.2, L2.1, U1.2 (VDD3P3), U1.3 (VDD3P3)
unnamed: D1.2 (A), R4.1
unnamed: C17.1, C18.1, D4.2 (A), U2.15 (VSTOR)
unnamed: D5.2 (A), Q1.2 (E)
unnamed: D5.1 (K), R17.2
unnamed: J1.A5 (CC1), R2#2.2
unnamed: J1.B5 (CC2), R3.2
unnamed: R15.2, R16.1
unnamed: C6.1, L1.1, U1.1 (LNA_IN)
unnamed: L3.2, U2.16 (LBST)
unnamed: R10.1, R13.2, U2.9 (OK_HYST)
unnamed: R7.1, R10.2, U2.10 (OK_PROG)
unnamed: R8.1, R11.2, U2.6 (VBAT_OV)
unnamed: R9.1, R12.2, U2.8 (VBAT_UV)
unnamed: R14.2, R15.1, U2.3 (VOC_SAMP)
unnamed: R11.1, R12.1, R13.1, U2.7 (VRDIV)
unnamed: C15.1, U2.4 (VREF_SAMP)
RX: J4.2, U1.27 (U0RXD/GPIO20)
SolarIN: C14.1, J6.4, L3.1, R14.1, U2.2 (VIN_DC)
SolarSYS: J6.1, Q1.1 (B), U2.11 (VBAT_OK)
TX: J4.1, U1.28 (U0TXD/GPIO21)
VBAT: J6.2, Q1.3 (C), U2.14 (VBAT)
VDD_SPI: C2.1, U1.18 (VDD_SPI/GPIO11)
XTAL_N: C3.2, U1.29 (XTAL_N), Y1.3
XTAL_P: C1.1, U1.30 (XTAL_P), Y1.1

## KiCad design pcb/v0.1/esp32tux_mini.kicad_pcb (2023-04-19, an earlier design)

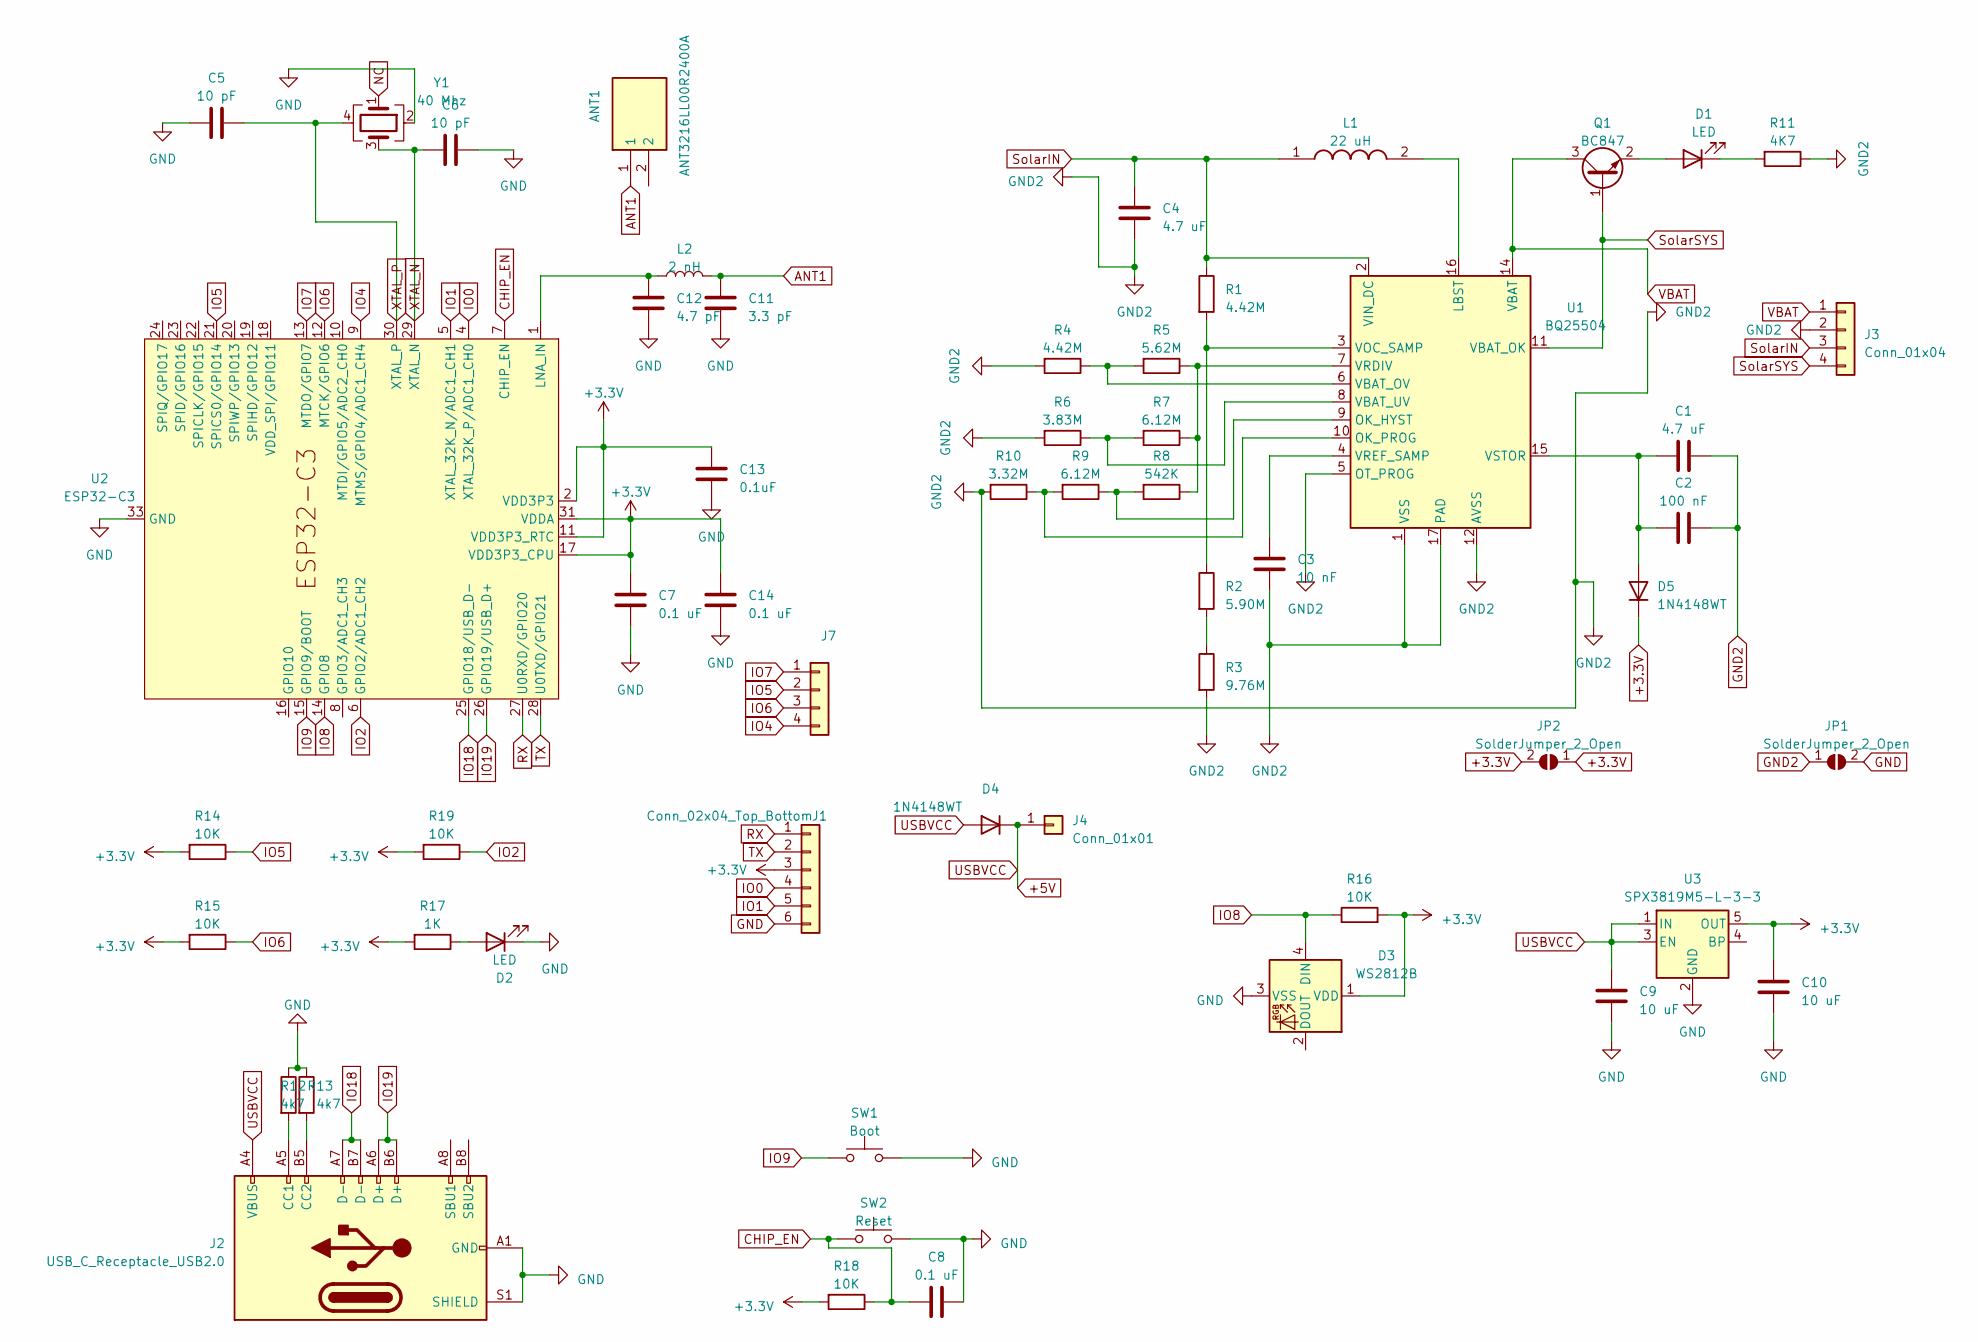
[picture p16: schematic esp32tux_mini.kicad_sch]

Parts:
ANT1: ANT3216LL00R2400A; Mouser Part Number 603-ANT3216LL00R2400
C1, C4: 4.7 uF; C_0603_1608Metric
C2: 100 nF; C_0402_1005Metric
C3: 10 nF; C_0402_1005Metric
C5, C6: 10 pF; C_0402_1005Metric
C7, C8, C14: 0.1 uF; C_0402_1005Metric
C9, C10: 10 uF; C_0603_1608Metric
C11: 3.3 pF; C_0402_1005Metric
C12: 4.7 pF; C_0402_1005Metric
C13: 0.1uF; C_0402_1005Metric
D1, D2: LED; LED_0402_1005Metric
D3: WS2812B; LED_WS2812B-2020_PLCC4_2.0x2.0mm
D4, D5: 1N4148WT; D_SOD-523
J1: Conn_02x04_Top_Bottom; PinHeader_1x06_P2.54mm_Vertical
J2: USB_C_Receptacle_USB2.0; USB_C_Receptacle_Palconn_UTC16-G
J3: Conn_01x04; PinHeader_1x04_P2.54mm_Vertical
J4: Conn_01x01; PinHeader_1x01_P2.54mm_Vertical
J7: Conn_02x04_Top_Bottom; PinHeader_1x04_P2.54mm_Vertical
JP1, JP2: SolderJumper_2_Open; SolderJumper-2_P1.3mm_Open_Pad1.0x1.5mm
L1: 22 uH; L_1008_2520Metric; Mouser Part Number 963-BRC2518T220K
L2: 2 nH; L_0402_1005Metric
Q1: BC847; SOT-23
R1, R4: 4.42M; R_0402_1005Metric
R2: 5.90M; R_0402_1005Metric
R3: 9.76M; R_0402_1005Metric
R5: 5.62M; R_0402_1005Metric
R6: 3.83M; R_0402_1005Metric
R7, R9: 6.12M; R_0402_1005Metric
R8: 542K; R_0402_1005Metric
R10: 3.32M; R_0402_1005Metric
R11: 4K7; R_0402_1005Metric
R12, R13: 4k7; R_0402_1005Metric
R14, R15, R16, R18, R19: 10K; R_0402_1005Metric
R17: 1K; R_0402_1005Metric
SW1: Boot; SW_Push_1P1T_NO_CK_KMR2
SW2: Reset; SW_Push_1P1T_NO_CK_KMR2
U1: BQ25504; VQFN-16-1EP_3x3mm_P0.5mm_EP1.68x1.68mm
U2: ESP32-C3; QFN-32-1EP_5x5mm_P0.5mm_EP3.45x3.45mm
U3: SPX3819M5-L-3-3; SOT-23-5
Y1: 40 Mhz; Crystal_SMD_3225-4Pin_3.2x2.5mm

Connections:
+3.3V: C7.1, C10.1, C13.1, C14.1, D3.1 (VDD), D5.1 (K), J1.3, JP2.1 (A), JP2.2 (B), R14.2, R15.2, R16.2, R17.2, R18.2, R19.2, U2.2 (VDD3P3), U2.3 (VDD3P3), U2.11 (VDD3P3_RTC), U2.17 (VDD3P3_CPU), U2.31 (VDDA), U2.32 (VDDA), U3.5 (OUT)
+5V: C9.1, D4.1 (K), D4.2 (A), J2.A4 (VBUS), J2.A9 (VBUS), J2.B4 (VBUS), J2.B9 (VBUS), J4.1, U3.1 (IN), U3.3 (EN)
ANT1: ANT1.1, C11.1, L2.2
CHIP_EN: C8.1, R18.1, SW2.1, U2.7 (CHIP_EN)
GND: C5.2, C6.1, C7.2, C8.2, C9.2, C10.2, C11.2, C12.2, C13.2, C14.2, D2.1 (K), D3.3 (VSS), J1.6, J2.A1 (GND), J2.A12 (GND), J2.B1 (GND), J2.B12 (GND), J2.S1 (SHIELD), JP1.2 (B), R12.1, R13.1, SW1.2, SW2.2, U2.33 (GND), U3.2 (GND), Y1.2
GND2: C1.2, C2.2, C3.2, C4.2, J3.2, JP1.1 (A), R3.2, R4.2, R6.2, R10.2, R11.1, U1.1 (VSS), U1.5 (OT_PROG), U1.12 (AVSS), U1.13 (VSS), U1.17 (PAD)
IO0: J1.4, U2.4 (XTAL_32K_P/ADC1_CH0)
IO1: J1.5, U2.5 (XTAL_32K_N/ADC1_CH1)
IO2: R19.1, U2.6 (GPIO2/ADC1_CH2)
IO4: J7.4, U2.9 (MTMS/GPIO4/ADC1_CH4)
IO5: J7.2, R14.1, U2.21 (SPICS0/GPIO14)
IO6: J7.3, R15.1, U2.12 (MTCK/GPIO6)
IO7: J7.1, U2.13 (MTDO/GPIO7)
IO8: D3.4 (DIN), R16.1, U2.14 (GPIO8)
IO9: SW1.1, U2.15 (GPIO9/BOOT)
IO18: J2.A7 (D-), J2.B7 (D-), U2.25 (GPIO18/USB_D-)
IO19: J2.A6 (D+), J2.B6 (D+), U2.26 (GPIO19/USB_D+)
NC: Y1.1
unnamed: D1.2 (A), Q1.2 (E)
unnamed: D1.1 (K), R11.2
unnamed: D2.2 (A), R17.1
unnamed: C1.1, C2.1, D5.2 (A), U1.15 (VSTOR)
unnamed: J2.A5 (CC1), R12.2
unnamed: J2.B5 (CC2), R13.2
unnamed: R2.2, R3.1
unnamed: L1.2, U1.16 (LBST)
unnamed: R8.2, R9.1, U1.9 (OK_HYST)
unnamed: R9.2, R10.1, U1.10 (OK_PROG)
unnamed: R4.1, R5.2, U1.6 (VBAT_OV)
unnamed: R6.1, R7.2, U1.8 (VBAT_UV)
unnamed: R1.2, R2.1, U1.3 (VOC_SAMP)
unnamed: R5.1, R7.1, R8.1, U1.7 (VRDIV)
unnamed: C3.1, U1.4 (VREF_SAMP)
unnamed: C12.1, L2.1, U2.1 (LNA_IN)
RX: J1.1, U2.27 (U0RXD/GPIO20)
SolarIN: C4.1, J3.3, L1.1, R1.1, U1.2 (VIN_DC)
SolarSYS: J3.4, Q1.1 (B), U1.11 (VBAT_OK)
TX: J1.2, U2.28 (U0TXD/GPIO21)
VBAT: J3.1, Q1.3 (C), U1.14 (VBAT)
XTAL_N: C6.2, U2.29 (XTAL_N), Y1.3
XTAL_P: C5.1, U2.30 (XTAL_P), Y1.4

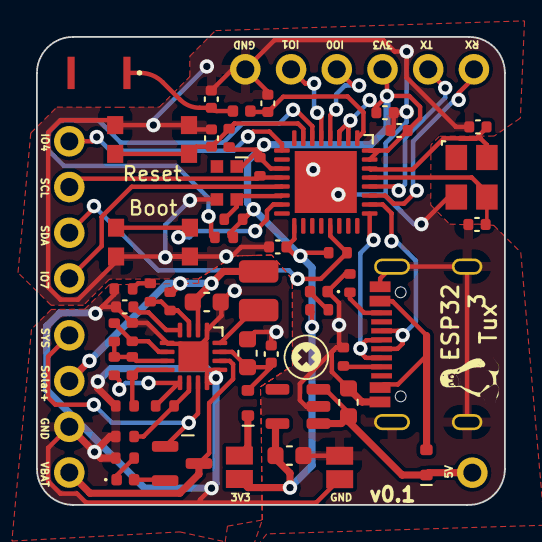
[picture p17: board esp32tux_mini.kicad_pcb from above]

Board: 2 copper layers, 26.0 x 26.0 mm, 55 parts (0 on the bottom side), 40 nets.

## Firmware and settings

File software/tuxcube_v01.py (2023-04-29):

import machine, gc, os, time, framebuf
from machine import Pin, Timer, SoftI2C
from phyphoxBLE import PhyphoxBLE, Experiment
from writer import Writer
import disp
from phoxdisp import app

from vl53l1x import VL53L1X
import bme280_float as bme280
from mpu6500 import MPU6500, SF_G, SF_DEG_S
from apds9900LITE import APDS9900LITE

i2c = SoftI2C(scl=Pin(6),sda=Pin(5),freq=400000)
button = Pin(7, Pin.IN, Pin.PULL_UP)

tof = VL53L1X(i2c)
bme = bme280.BME280(i2c=i2c)
optic = APDS9900LITE(i2c)
optic.prox.enableSensor()

#Button press functions + debounce
def on_pressed(timer):
    global butstate
    butstate = (butstate + 1) % 6

def debounce(pin):
    timer.init(mode=Timer.ONE_SHOT, period=50, callback=on_pressed)

#Show memory and space usage
def free(full=False):
  gc.collect()
  F = gc.mem_free()
  A = gc.mem_alloc()
  T = F+A
  P = '{0:.2f}%'.format(F/T*100)
  if not full: return P
  else : return ('Total:{0} Free:{1} ({2})'.format(T,F,P))

def df():
  s = os.statvfs('//')
  return ('{0} MB'.format((s[0]*s[3])/1048576))
  
#Initialize App Design and output data to phyphox
def cube(x):
    global butstate
    disp.menu(x)
    app(x,p)
    while x == butstate:
        m = sens(x)
        disp.data(x,m)
        p.write(m[0],m[1],m[2],m[3])  #Send value to phyphox
        time.sleep_ms(250)
        gc.mem_free()

def sens(x):
    if x == 0:
        data = list(bme.values)+[0]
    elif x == 1:
        data = list(bme.values)+[0]
        print("Hallo")
    elif x == 2:
        data = list(bme.values)+[0]
        print("Hallo")
    elif x == 3:
        data = list(bme.values)+[0]
        print("Hallo")
    elif x == 4:
        data = list(bme.values)+[0]
        print("Hallo")
    else:
        data = list(bme.values)+[0]
        print("Hallo")
    return data

# Tux³ Cube Routine
disp.startani()

butstate = 0
timer = Timer(0)
p = PhyphoxBLE()
editValue = 0.0
firstCall = True
button.irq(debounce, Pin.IRQ_RISING)

while True:
    cube(butstate)
    time.sleep(0.1)
    gc.mem_free()
    print(df(),free())

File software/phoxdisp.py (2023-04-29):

from phyphoxBLE import Experiment
import time
import random

def app(butstate,p):
    if butstate == 0:
        device = "Sensor BME280"
        desc = "Sensor zum Messen von Temperatur, Luftdruck und Luftfeuchtigkeit"
        view = ["Temperatur T", "Temp. 1"]
        a = ["Temperaturverlauf", "s", "C", "t", "T", 1]
        b = ["Druckverlauf", "s", "hPa", "t", "p", 1]
        c = ["Temperaturverlauf","s","C","t","T",1]
        ex =["BME280 data", "Temperatur","Druck","Temp1","Temp2"]
    elif butstate ==1:
        device = "Sensor BME282"
        desc = "Sensor zum Messen von Temperatur, Luftdruck und Luftfeuchtigkeit"
        view = ["Temperatur T  Druck p", "Temp. 1 & Temp. 2"]
        a = ["Temperaturverlauf", "s", "C", "t", "T", 1]
        b = ["Druckverlauf", "s", "hPa", "t", "p", 1]
        c = ["Temperaturverlauf","s","C","t","T",1]
        ex =["BME280 data", "Temperatur","Druck","Temp1","Temp2"]
    elif butstate ==2:
        device = "Sensor BME283"
        desc = "Sensor zum Messen von Temperatur, Luftdruck und Luftfeuchtigkeit"
        view = ["Temperatur T & Druck p", "Temp. 1 & Temp. 2"]
        a = ["Temperaturverlauf", "s", "°C", "t", "T", 1]
        b = ["Druckverlauf", "s", "hPa", "t", "p", 1]
        c = ["Temperaturverlauf","s","°C","t","T",1]
        ex =["BME280 data", "Temperatur","Druck","Temp1","Temp2"]
    elif butstate ==3:
        device = "Sensor BME284"
        desc = "Sensor zum Messen von Temperatur, Luftdruck und Luftfeuchtigkeit"
        view = ["Temperatur T & Druck p", "Temp. 1 & Temp. 2"]
        a = ["Temperaturverlauf", "s", "°C", "t", "T", 1]
        b = ["Druckverlauf", "s", "hPa", "t", "p", 1]
        c = ["Temperaturverlauf","s","°C","t","T",1]
        ex =["BME280 data", "Temperatur","Druck","Temp1","Temp2"]
    elif butstate ==4:
        device = "Sensor BME285"
        desc = "Sensor zum Messen von Temperatur, Luftdruck und Luftfeuchtigkeit"
        view = ["Temperatur T & Druck p", "Temp. 1 & Temp. 2"]
        a = ["Temperaturverlauf", "s", "°C", "t", "T", 1]
        b = ["Druckverlauf", "s", "hPa", "t", "p", 1]
        c = ["Temperaturverlauf","s","°C","t","T",1]
        ex =["BME280 data", "Temperatur","Druck","Temp1","Temp2"]
    else:
        device = "Sensor BME281"
        desc = "Sensor zum Messen von Temperatur, Luftdruck und Luftfeuchtigkeit"
        view = ["Temperatur T & Druck p", "Temp. 1 & Temp. 2"]
        a = ["Temperaturverlauf", "s", "°C", "t", "T", 1]
        b = ["Druckverlauf", "s", "hPa", "t", "p", 1]
        c = ["Temperaturverlauf","s","°C","t","T",1]
        ex =["BME280 data", "Temperatur","Druck","Temp1","Temp2"]
 
    p.start(device)
    p._write_callback = receivedData
    #Experiment
    plot = Experiment()   #generate experiment on Arduino which plot random values
    plot.setTitle(device)
    plot.setCategory("Tux Cube")
    plot.setDescription(desc)

    #View
    firstView = Experiment.View()
    firstView.setLabel(view[0]) #Create a "view"
    secondView = Experiment.View()
    secondView.setLabel(view[1]) #Create a "view"

    #Graph
    firstGraph = Experiment.Graph()   #Create graph which will plot random numbers over time
    firstGraph.setLabel(a[0])
    firstGraph.setUnitX(a[1])
    firstGraph.setUnitY(a[2])
    firstGraph.setLabelX(a[3])
    firstGraph.setLabelY(a[4])
    firstGraph.setXPrecision(a[5])                 #The amount of digits shown after the decimal point
    firstGraph.setYPrecision(a[5])

    firstGraph.setChannel(0, 1)

    #Second Graph
    secondGraph = Experiment.Graph()   #Create graph which will plot random numbers over time
    secondGraph.setLabel(b[0])
    secondGraph.setUnitX(b[1])
    secondGraph.setUnitY(b[2])
    secondGraph.setLabelX(b[3])
    secondGraph.setLabelY(b[4])
    secondGraph.setXPrecision(b[5])                 #The amount of digits shown after the decimal point
    secondGraph.setYPrecision(b[5])
    secondGraph.setColor("2E728E")                #Sets Color of line

    secondGraph.setChannel(0, 2)
    
    #Third Graph
    thirdGraph = Experiment.Graph()   #Create graph which will plot random numbers over time
    thirdGraph.setLabel(c[0])
    thirdGraph.setUnitX(c[1])
    thirdGraph.setUnitY(c[2])
    thirdGraph.setLabelX(c[3])
    thirdGraph.setLabelY(c[4])
    thirdGraph.setXPrecision(c[5])                 #The amount of digits shown after the decimal point
    thirdGraph.setYPrecision(c[5])
    thirdGraph.setColor("2E728E")                #Sets Color of line

    thirdGraph.setChannel(0, 3)

    
    #Forth Graph
    forthGraph = Experiment.Graph()   #Create graph which will plot random numbers over time
    forthGraph.setLabel(c[0])
    forthGraph.setUnitX(c[1])
    forthGraph.setUnitY(c[2])
    forthGraph.setLabelX(c[3])
    forthGraph.setLabelY(c[4])
    forthGraph.setXPrecision(c[5])                 #The amount of digits shown after the decimal point
    forthGraph.setYPrecision(c[5])
    forthGraph.setColor("2E728E")                #Sets Color of line
    
    forthGraph.setChannel(0, 4)

    
    #Export
    mySet = Experiment.ExportSet()        #Provides exporting the data to excel etc.
    mySet.setLabel(ex[0])

    myData1 = Experiment.ExportData() 
    myData1.setLabel(ex[1])
    myData1.setDatachannel(1)

    myData2 = Experiment.ExportData() 
    myData2.setLabel(ex[2])
    myData2.setDatachannel(2)
    
    myData3 = Experiment.ExportData() 
    myData3.setLabel(ex[3])
    myData3.setDatachannel(2)
    
    myData4 = Experiment.ExportData() 
    myData4.setLabel(ex[4])
    myData4.setDatachannel(4)

    #attach to experiment

    firstView.addElement(firstGraph)            #attach graph to view
    firstView.addElement(secondGraph)            #attach second graph to view
    secondView.addElement(thirdGraph)                #attach info to view
    secondView.addElement(forthGraph)
    plot.addView(firstView)         #attach view to experiment
    plot.addView(secondView)
    mySet.addElement(myData1)                   #attach data to exportSet
    mySet.addElement(myData2)                   #attach data to exportSet
    mySet.addElement(myData3)                   #attach data to exportSet
    mySet.addElement(myData4)
    plot.addExportSet(mySet)        #attach exportSet to experiment
    p.addExperiment(plot) #attach experiment to server

def receivedData():          # get data from PhyPhox app
    global editValue
    global firstCall
    if not firstCall:
        editValue = float(p.read())
    firstCall = False

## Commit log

2023-04-19 Add files via upload
    ESP32 first PCB Design v0.1
    [esp32tux_mini.kicad_pcb, esp32tux_mini.kicad_sch]
2023-04-19 Add files via upload
    PDF of schematics
2023-04-24 FreeCAD design and stl files of first case draft
    [TuxCube3_case_v01.FCStd, cube_inside.stl, cube_outside.stl]
2023-04-25 case v02
    [cube_inside.stl, cube_outside.stl]
2023-05-22 ESP32-Tux-Mini v01 PCB
    Mini PCB without BQ25504 solar charging circuit, 20x20mm
    [bom.csv, designators.csv, positions.csv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]
2026-03-15 PCB v0.3 with ESP32-C5 chip and TP4056
    TP4056 charging circuit instead of BQ25504
    [tuxmini_v03.csv, tuxmini_v03.kicad_pcb, tuxmini_v03.kicad_sch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]
2026-03-30 Swaped D- and D+ pin on ESP32-C5 pinout
    [tuxmini_v03.kicad_pcb, tuxmini_v03.kicad_sch]
2026-04-10 Create esp32-c5
2026-04-12 add schematics as pdf file

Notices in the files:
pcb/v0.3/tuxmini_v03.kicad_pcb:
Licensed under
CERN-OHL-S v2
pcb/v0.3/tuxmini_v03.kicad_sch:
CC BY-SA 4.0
